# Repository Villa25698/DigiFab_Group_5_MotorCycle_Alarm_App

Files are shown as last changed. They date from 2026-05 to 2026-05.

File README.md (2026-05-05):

# MC Alarm — Motorcycle hazard-detection system

An accessible, retrofit-oriented warning device that detects motorcycle
speed wobble events and broadcasts a synchronised alert through three
independent channels: an LED hazard triangle on the bike, a wirelessly
switched relay that flashes the existing hazard lamps, and a full-screen
takeover on the rider's smartphone with a 5-second arming countdown.

Built for the ITI60020 *Digital Fabrication and Making* course at Østfold
University College, Spring 2026, in alignment with United Nations
Sustainable Development Goal Target 11.2 on safe, accessible, and
sustainable transport.

```
 ┌────────────────────┐    BLE GATT    ┌────────────────────────┐
 │  Flutter phone app │ ◄────────────► │  ESP32-C3  "master"    │
 └────────────────────┘                │  - MPU-6050 gyro       │
                                       │  - 8x8 LED matrix      │
                                       │  - 5W speaker (siren)  │
                                       │  - Test / OFF buttons  │
                                       └──────┬─────────────────┘
                                              │ ESP-NOW
                                              ▼
                                       ┌────────────────────────┐
                                       │  ESP32-C3 "slave"      │
                                       │  - 5V relay → hazards  │
                                       └────────────────────────┘
```

## Repository layout

| Folder | What it is |
| --- | --- |
| [`master/`](master) | ESP32-C3 firmware for the master node (gyro detection + siren + matrix + BLE + ESP-NOW) |
| [`slave_esp2_0/`](slave_esp2_0) | ESP32-C3 firmware for the hazard-relay slave |
| [`app/`](app) | Flutter companion app (Android) |
| [`ble_test/`](ble_test) | Minimal BLE-only test sketch — useful when bringing up a fresh ESP32-C3 |

## Hardware

**Electronics**
- 2× ESP32-C3 DevKitM-1
- 1× InvenSense MPU-6050 6-DoF IMU (I²C, addr `0x68`)
- 1× HT16K33 8x8 LED matrix backpack (I²C, addr `0x70`)
- 1× 5V single-channel relay module → motorcycle hazard light wiring
- 1× 40 mm 4 Ω 5 W speaker
- 2× metal pushbuttons (test alarm + off alarm)

**Mechanical (digitally fabricated)**
- 3D printed PETG enclosures: master case, slave case, and two pink end-cap holders for the indicator bulbs
- 3D printed TPU strap insert (25% infill, fuzzy-skin texture) for vibration damping and grip on the handlebar
- 3D printed PETG handlebar clamp halves (two diameter variants: 25.0 mm and 35.4 mm)
- Laser-cut MDF base panels closing the enclosures
- Laser-cut acrylic mounting plate on the Segway used as a mock motorcycle test platform

## Pin map (master)

The MPU-6050 and the LED matrix share **the same I²C bus** on GPIO 2/3,
distinguished by their different I²C addresses (`0x68` and `0x70`).

| Pin | Function |
| --- | --- |
| GPIO 4  | Test alarm button (INPUT_PULLUP) |
| GPIO 5  | Off alarm button (INPUT_PULLUP) |
| GPIO 7  | Speaker / piezo |
| GPIO 2  | Shared I²C SDA (MPU-6050 + matrix) |
| GPIO 3  | Shared I²C SCL (MPU-6050 + matrix) |

## Pin map (slave)

| Pin | Function |
| --- | --- |
| GPIO 18 | Relay control |

The relay polarity is set by two named constants at the top of
[`slave_esp2_0/slave_esp2_0.ino`](slave_esp2_0/slave_esp2_0.ino):

```cpp
const int RELAY_ON  = HIGH;   // pin level that lights the hazards
const int RELAY_OFF = LOW;    // pin level that turns them off
```

If the lights are on at boot, swap the two values.

## Firmware quick start

1. Install **Arduino IDE** with the **esp32 by Espressif Systems** board
   support package (core 3.x).
2. Install Arduino libraries: `Adafruit MPU6050`, `Adafruit Unified Sensor`,
   `Adafruit GFX`, `Adafruit LED Backpack`.
3. Open [`master/master.ino`](master/master.ino), select board
   `ESP32C3 Dev Module`, flash.
4. Open [`slave_esp2_0/slave_esp2_0.ino`](slave_esp2_0/slave_esp2_0.ino),
   set `#define NODE_ID 1` (each slave needs a unique id), flash.
5. The slave's MAC must match the `slave1[]` array in `master/master.ino`.
   Read the MAC from the slave's Serial Monitor at boot and update the
   master if needed.

## App quick start

See [`app/README.md`](app/README.md) — it pins the exact Flutter, Android
SDK, NDK, and plugin versions that work on Windows. **Use those versions
or you will spend hours fighting toolchain bugs.**

## BLE protocol

Service UUID: `a8a9b000-7c1f-4d2a-9e6b-2b0f3a7c0001`

| Char | UUID suffix | Props | Payload |
| --- | --- | --- | --- |
| alarmState  | `…0002` | Read, Notify | `uint8` 0/1 |
| wobbleEvent | `…0003` | Read, Notify | `uint8` counter |
| command | `…0004` | Write | `uint8` 0=stop, 1=manual, 2=toggle |
| nodeStatus  | `…0005` | Read, Notify | `uint8` bitmask, bit n = slave n+1 online |

## Wobble detection

The detector checks the strongest gyroscope axis per sample for sustained
back-and-forth motion. A trip requires **N sign reversals at >T rad/s
within W milliseconds** of each other.

| Profile | Threshold (T) | Sign reversals (N) | Window (W) |
| --- | --- | --- | --- |
| **Demo (default in this repo)** | 1.0 rad/s | 3 | 800 ms |
| **Production (recommended for on-bike use)** | 2.5 rad/s | 4 | 600 ms |

Demo values are easy to trigger by hand for testing. **Before mounting
on a real motorcycle, raise the values to the production profile** so road
surface vibration and engine harmonics don't cause false triggers. The
constants are at the top of `checkForWobble()` in
[`master/master.ino`](master/master.ino).

## Demo Guide
Follow these steps to power on the system and simulate motorcycle death wobble event

1. Powering on
   * Open the enclousures: Carefully open the lids of both the master(handlebar module) and the slave(light relay module)(CAUTION! Handle the Slave module (Lower box) carefullt when open, as interal components may be loose)
   * Acticate Power: Locate the battery switches and toggle them on.
   * Once the LEDs on the esp32 boards indicate power, screw the lids back on
   * Connect the 12v battery to a outlet
2. Simulating the death wobble
   * Place both hand on the handlebar grips
   * Mimic a motorcycle death wobble by making rapid left and right steering motions
   * You will have to do back and fourth motions until the LED Matric will display a hazard triangle. (It will also display on your phone if app us being used)
3. Managing the alarm
   * When the the alarm is triggered will you have a 5 second grace period to turn it off before the alarm starts. Press the Stop button on top of the master module or Stop button on your phone to turn prevent the siren and hazard light from activating
   * When the countdown reaches zero, will there be an aduble sound, matrix will keep blinking, and the hazard lights will start blinking. Press Stop on the box or phone to return the system to idle state. 

## Wobble alarm flow

1. **Idle**: master continuously samples the IMU.
2. **Detected**: wobble pattern matches the active profile → master sends
   a BLE wobble notify → phone pops the full-screen emergency takeover
   with a **5-second arming countdown**, master lights the hazard
   triangle on the LED matrix.
3. **Grace period (5 s)**: rider can abort by either:
   - pressing the **OFF button** on the master, OR
   - pressing **STOP** on the phone.
   Either action prevents the siren and the slave relay from firing.
4. **Alarm**: if 5 s elapse with no abort, the master fires the siren,
   broadcasts the alarm state to the slave over ESP-NOW, and the slave
   pulses its relay in synchrony, flashing the motorcycle's hazard
   lamps.
5. **Stop**: rider presses STOP (phone or button) → siren and relay
   silenced.
6. **Cooldown (3 s)**: wobble detection is suppressed so the speaker's own
   vibration cannot immediately re-trigger the alarm. After cooldown, the
   system returns to idle.

## Course paper

The accompanying 4-6 page extended academic abstract describes the
design rationale, related work, fabrication process, validation
results, and discussion. Submitted as part of the ITI60020 exam, May
2026.

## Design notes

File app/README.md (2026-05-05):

# MC Alarm — Flutter companion app

Connects to the MC-Alarm ESP32-C3 gateway over BLE, shows live status, and
takes over the screen when a speed-wobble event fires.

```
 Phone (this app)
     │  BLE GATT
 ESP32-C3 "master"  ──────►  ESP-NOW  ──────► ESP32-C3 slave nodes
```

## Required toolchain (READ THIS BEFORE INSTALLING)

We hit a wall of Windows long-path / Dart compiler bugs on newer Flutter
versions. Use **exactly** these versions and you'll skip the pain.

| Tool | Version | Notes |
| --- | --- | ----- |
| Flutter SDK | **3.24.5 (stable)** | Newer 3.27+ has Windows long-path bugs and a JSON-escape bug in `.flutter-plugins-dependencies` that breaks plugin discovery |
| Dart | bundled with Flutter | comes with 3.24.5 — don't install separately |
| Android Studio | Hedgehog (2023.1) or newer | needed for the Android SDK + cmdline-tools, not as the editor |
| Android SDK | API 34 / build-tools 34 | install via Android Studio's SDK Manager |
| Android NDK | **27.0.12077973** | required by `flutter_local_notifications` — set in `android/app/build.gradle.kts` |
| Java | 17 | Flutter 3.24 picks this up from Android Studio's bundled JDK |
| `flutter_blue_plus` | **1.31.17** | 1.32+ split into platform packages with new Gradle conventions; stay on 1.31.x |
| `permission_handler` | **11.3.1** | works cleanly with Flutter 3.24 |
| `flutter_local_notifications` | **17.2.3** | 17.0.x has a Java compile error (`bigLargeIcon ambiguous`) |

### Get Flutter 3.24.5

```bash
git clone https://github.com/flutter/flutter.git -b 3.24.5 C:\flutter
# add C:\flutter\bin to your PATH
flutter --version    # verify "Flutter 3.24.5 • channel stable"
```

If you already have a different Flutter version installed, switch with:
```bash
flutter version 3.24.5
```

### Avoid deep folder paths on Windows

Clone the repo to a short path (e.g. `C:\mc-alarm` not
`C:\Users\you\Documents\GitHub\…`). Flutter's plugin tooling chokes on
paths longer than ~150 chars on Windows.

## First-time setup

Flutter doesn't ship the platform scaffolds in source control, so generate
them once — then let the files we've committed here take over.

```bash
cd app
flutter create . --platforms=android,ios --org com.digifab --project-name mc_alarm
flutter pub get
```

`flutter create .` generates `android/`, `ios/`, `build.gradle`, etc. without
touching existing files — so `lib/`, `pubspec.yaml`, `analysis_options.yaml`
and `android/app/src/main/AndroidManifest.xml` stay as provided.

### iOS only — merge Info.plist keys

Open `ios/Runner/Info.plist` and add the keys listed in
`ios/Runner/Info.plist.additions`. They grant Bluetooth + Location
permission strings that Apple requires at App Store submission time.

### Android only — minimum SDK

Edit `android/app/build.gradle`, set:
```gradle
defaultConfig {
    minSdkVersion 23   // flutter_blue_plus requires 21+, we use 23 for safety
    targetSdkVersion 34
}
```

## Running

```bash
flutter run -d <device>           # pick a real Android phone for BLE
```

BLE does not work on the Android emulator — test on a real phone.

## GATT protocol

Service UUID: `a8a9b000-7c1f-4d2a-9e6b-2b0f3a7c0001`

| Characteristic | UUID suffix | Props | Payload |
| --- | --- | ----- | --- |
| alarmState  | `...0002` | Read, Notify | `uint8` 0/1 |
| wobbleEvent | `...0003` | Notify | `uint8` counter |
| command | `...0004` | Write | `uint8` 0=stop, 1=manual, 2=toggle hazard |
| nodeStatus  | `...0005` | Read, Notify | `uint8` bitmask, bit n = slave n+1 online |

Source of truth: [master/master.ino](../master/master.ino).

## Emergency screen behaviour

When the gateway sends a `wobbleEvent` notification:

- **Foreground**: the app pushes `WobbleScreen` over the current route.
- **Background (Android)**: a high-priority `USE_FULL_SCREEN_INTENT`
  notification fires. Android promotes our activity to the foreground
  (`showWhenLocked=true`, `turnScreenOn=true` in the manifest). User can
  also tap the persistent notification.
- **Background (iOS)**: a critical-sound notification is shown. iOS does
  not permit an app to force itself to the foreground — this is a
  platform limitation, not a bug. The user must tap the banner.

The `STOP` button on the wobble screen writes `command=0` back to the
gateway, which silences the siren and clears the relays via ESP-NOW.

## Directory layout

```
lib/
├── main.dart                 App entry, root router, wobble listener
├── bluetooth/
│   ├── ble_constants.dart    UUIDs & command codes (kept in sync with firmware)
│   └── ble_service.dart      ChangeNotifier-owned BLE connection
├── services/
│   └── notification_service.dart   Full-screen-intent notification plumbing
├── screens/
│   ├── welcome_screen.dart
│   ├── permissions_screen.dart
│   ├── scan_screen.dart
│   ├── dashboard_screen.dart
│   └── wobble_screen.dart
└── theme/app_theme.dart      High-contrast, oversized-touch-target theme
```

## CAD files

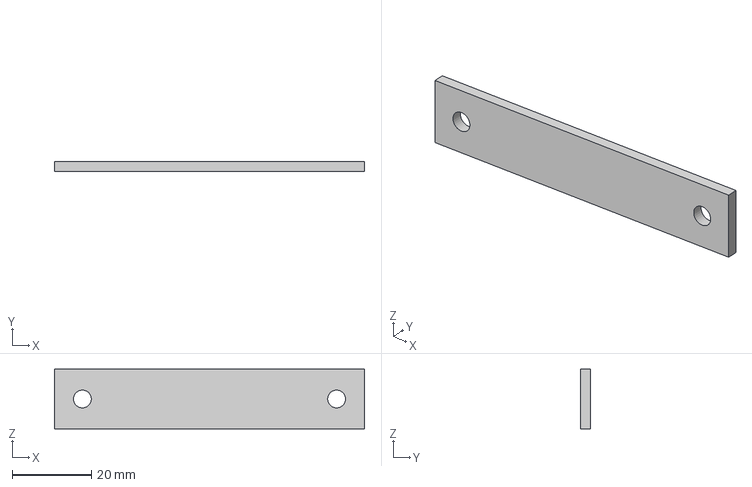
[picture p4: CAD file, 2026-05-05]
3d_models/reim_main.3mf
78.0 x 2.50 x 15.0 mm

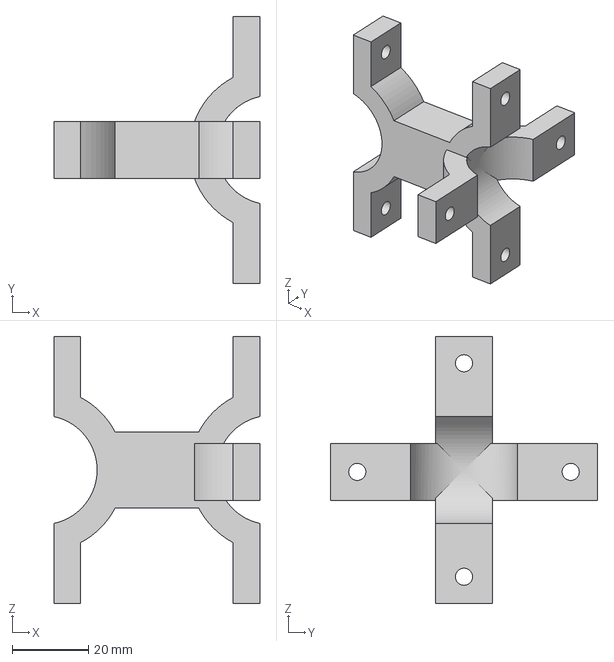
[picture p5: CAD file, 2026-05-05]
3d_models/ClampMainWstaff.3mf
54.0 x 70.0 x 70.0 mm

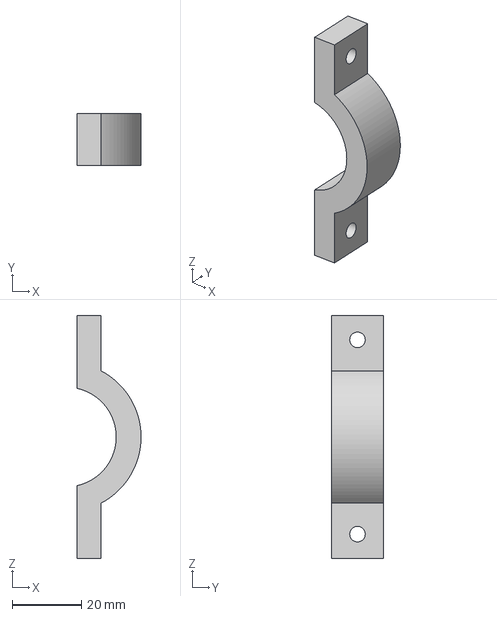
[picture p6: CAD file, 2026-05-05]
3d_models/ClampMain.3mf
18.5 x 15.0 x 70.0 mm

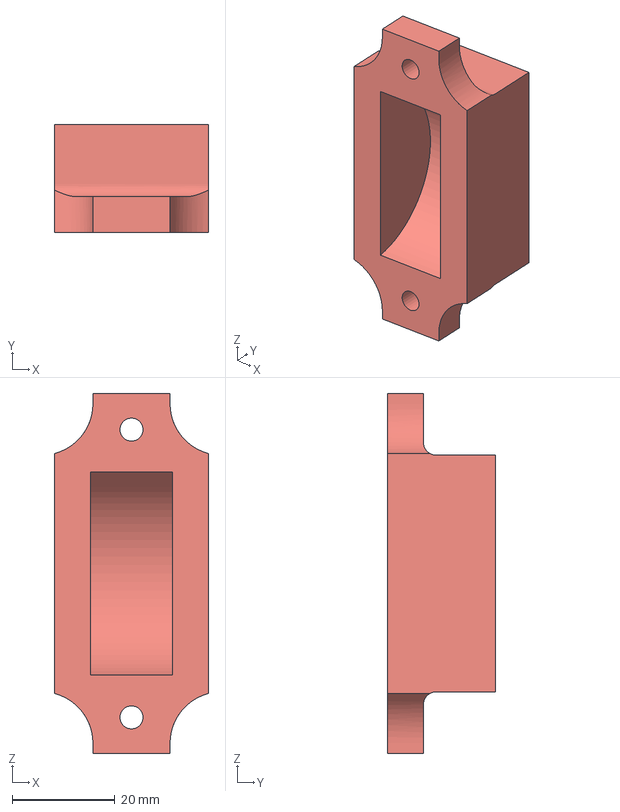
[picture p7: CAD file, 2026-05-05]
3d_models/attachment.3mf
30.0 x 21.0 x 70.0 mm

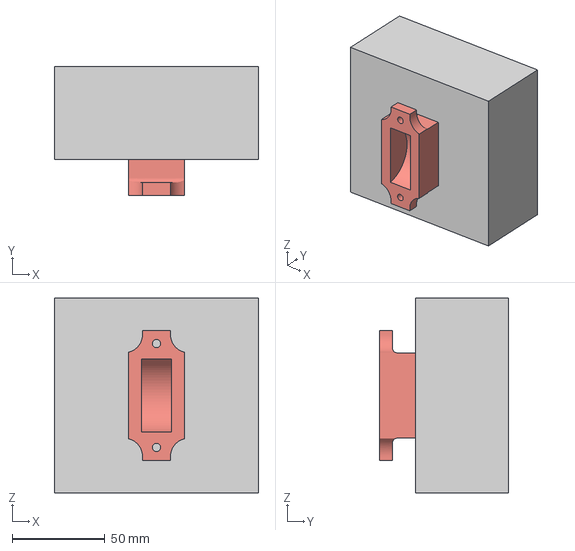
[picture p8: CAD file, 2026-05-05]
3d_models/User_box_w_attachment.3mf
110.0 x 69.5 x 105.0 mm

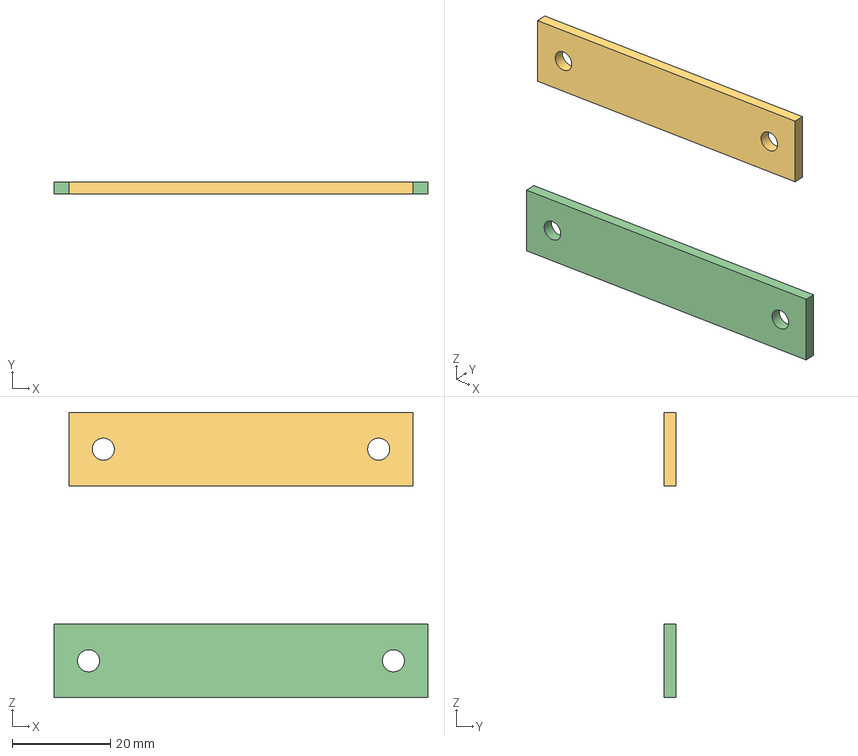
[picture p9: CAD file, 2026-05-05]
3d_models/straps_w_flat.3mf
76.0 x 2.50 x 58.0 mm

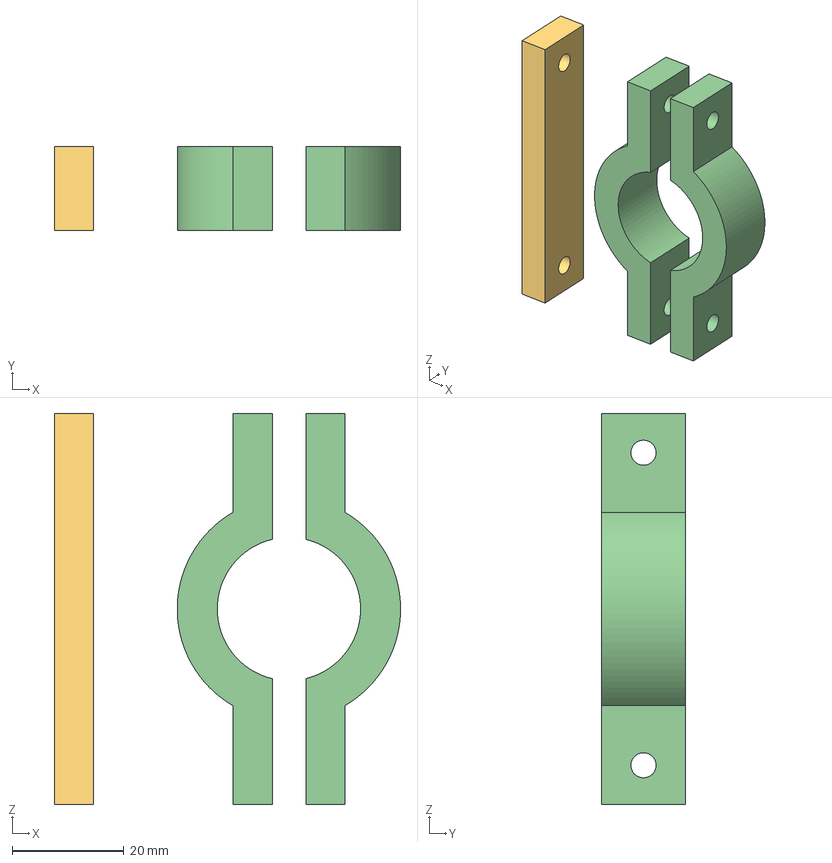
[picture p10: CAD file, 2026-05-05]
3d_models/clamps_w_flat.3mf
62.0 x 15.0 x 70.0 mm

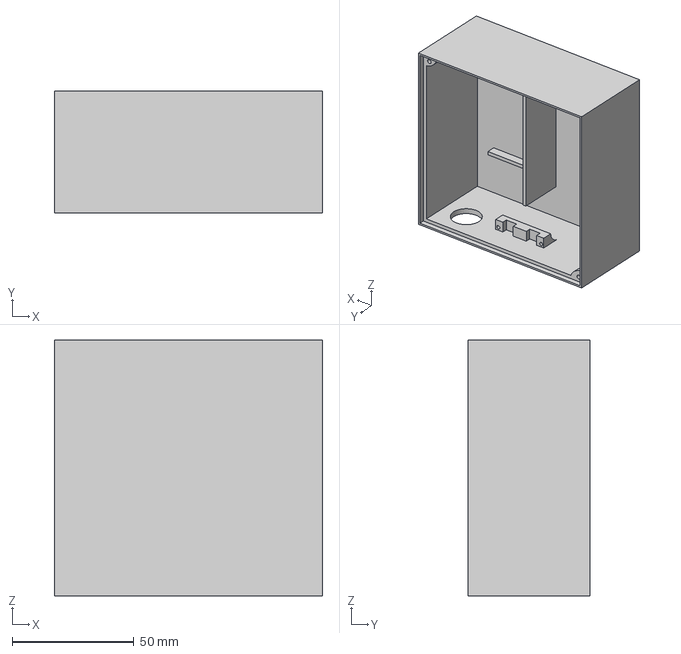
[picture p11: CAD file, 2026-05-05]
3d_models/user_box.3mf
110.0 x 50.0 x 105.0 mm

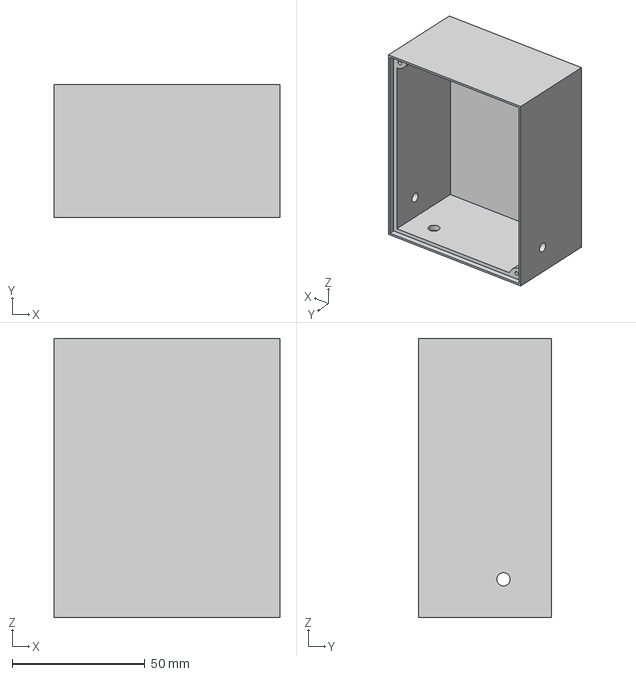
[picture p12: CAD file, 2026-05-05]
3d_models/comp_box.3mf
85.0 x 50.0 x 105.0 mm

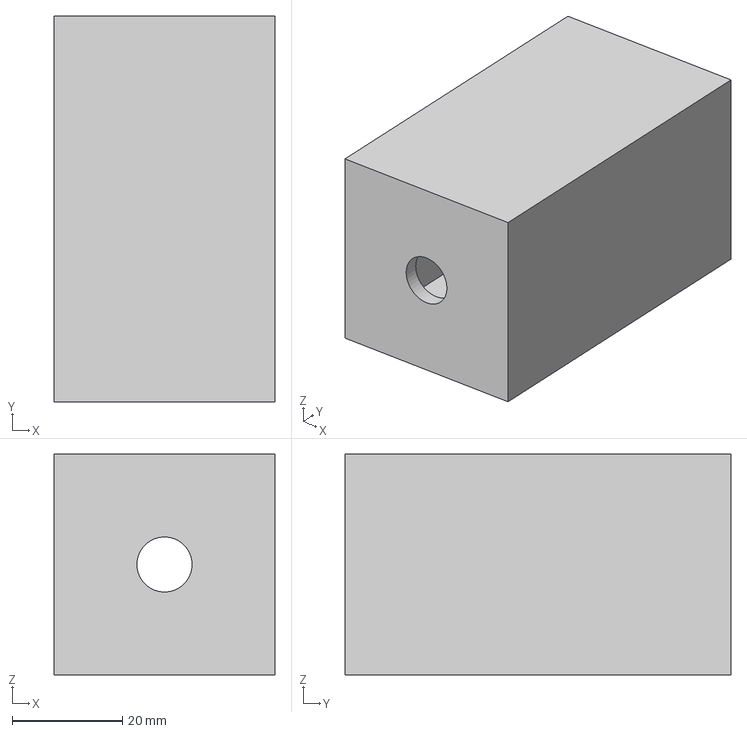
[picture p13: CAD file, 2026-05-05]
3d_models/light_attachment.3mf
40.0 x 70.0 x 40.0 mm

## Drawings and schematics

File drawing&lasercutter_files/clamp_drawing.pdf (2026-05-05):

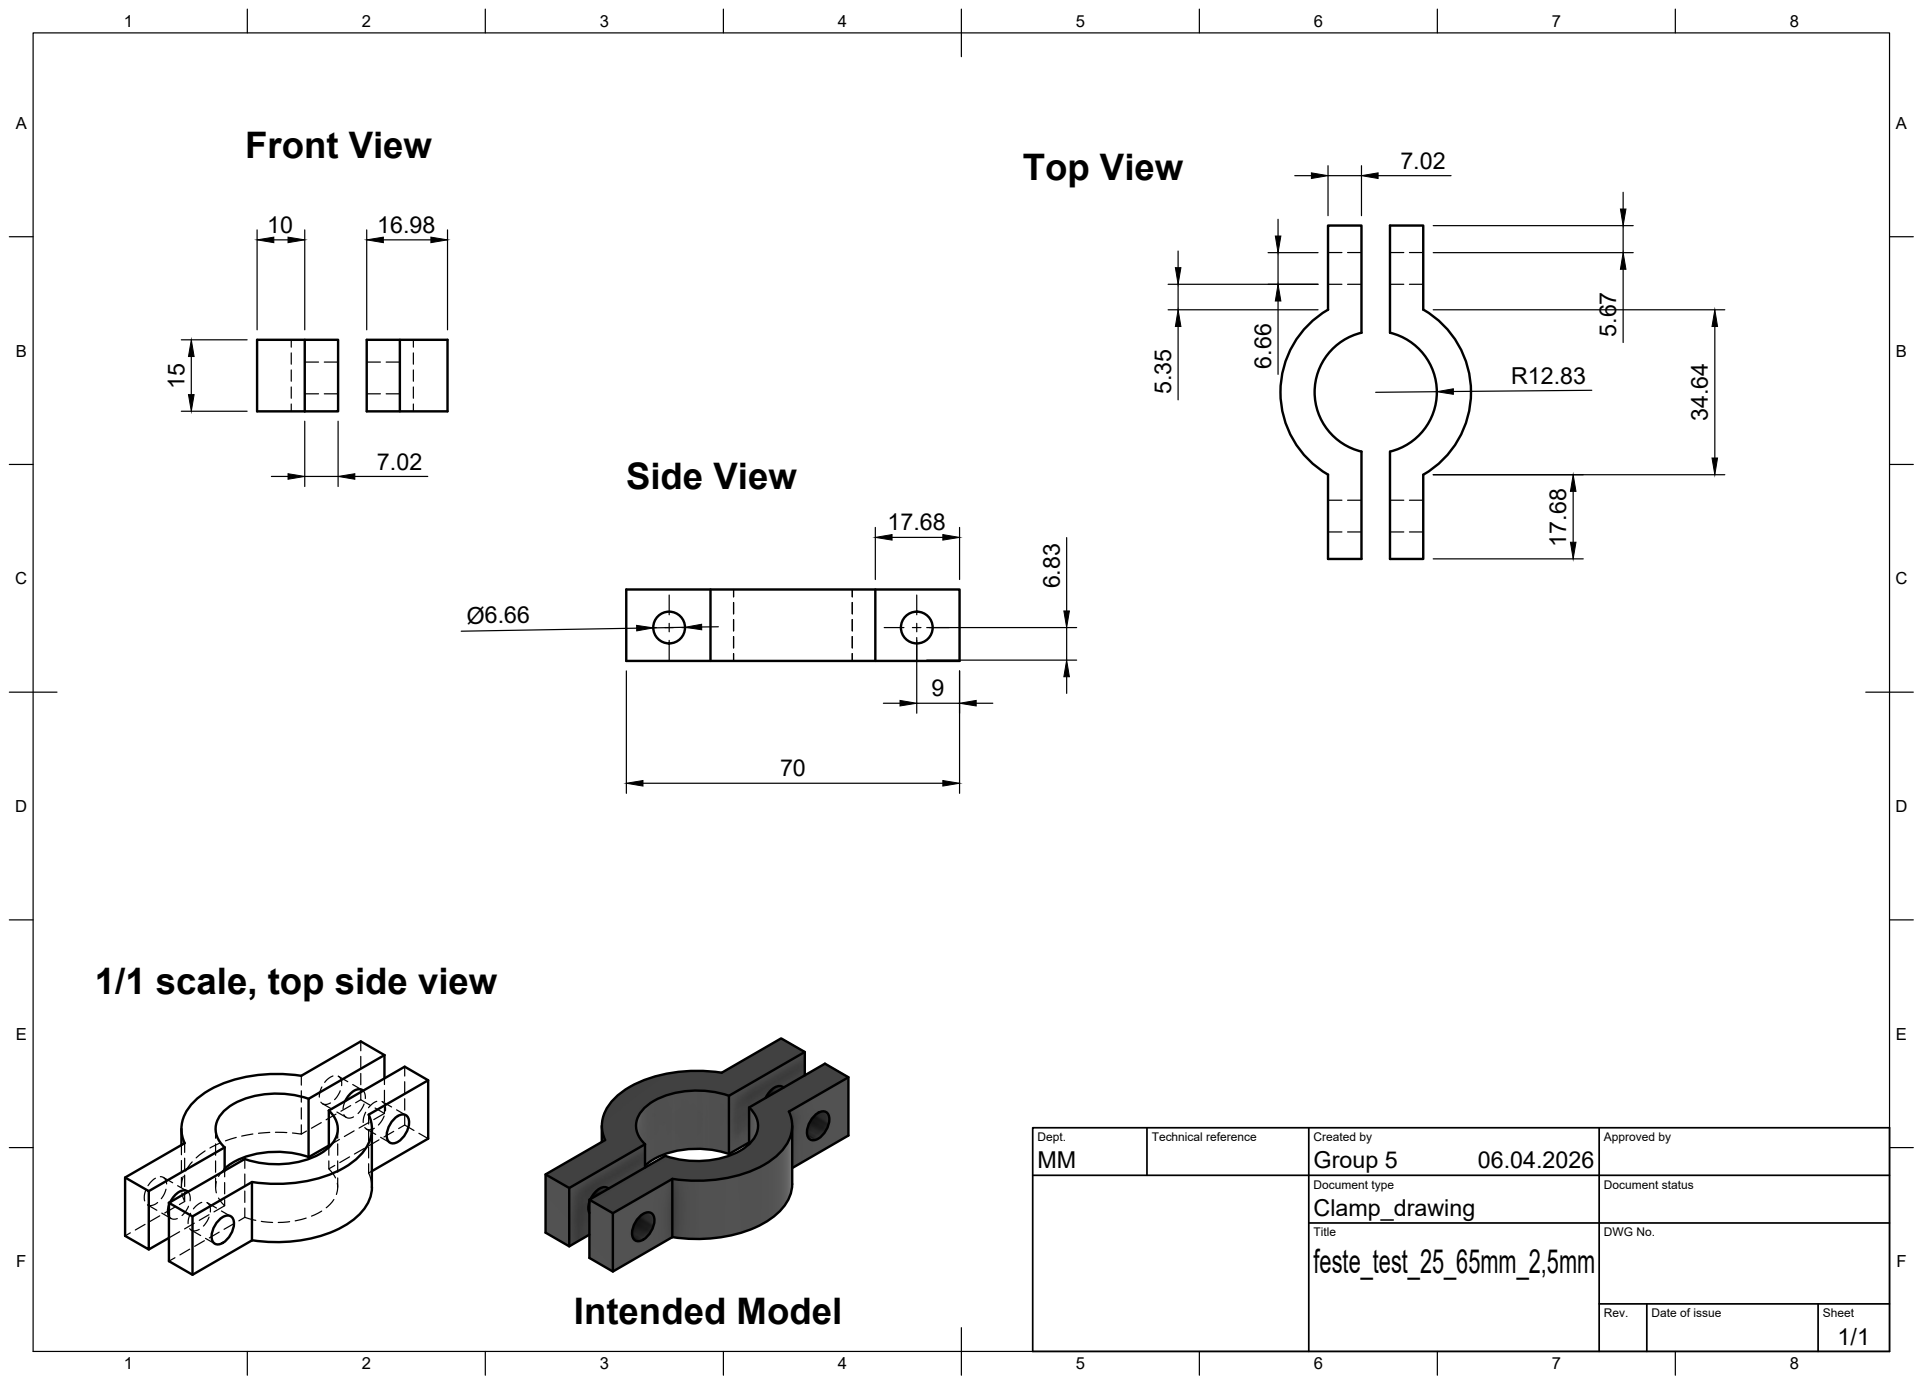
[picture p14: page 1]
Title; DWG No.; Rev.; Date of issue; Sheet; Group 5 15; Front View; Side View; Top View; Intended Model

1/1 scale, top side view

Dept. | Technical reference | Created by 06.04.2026 | Approved by

Document type Clamp_drawing | Document status

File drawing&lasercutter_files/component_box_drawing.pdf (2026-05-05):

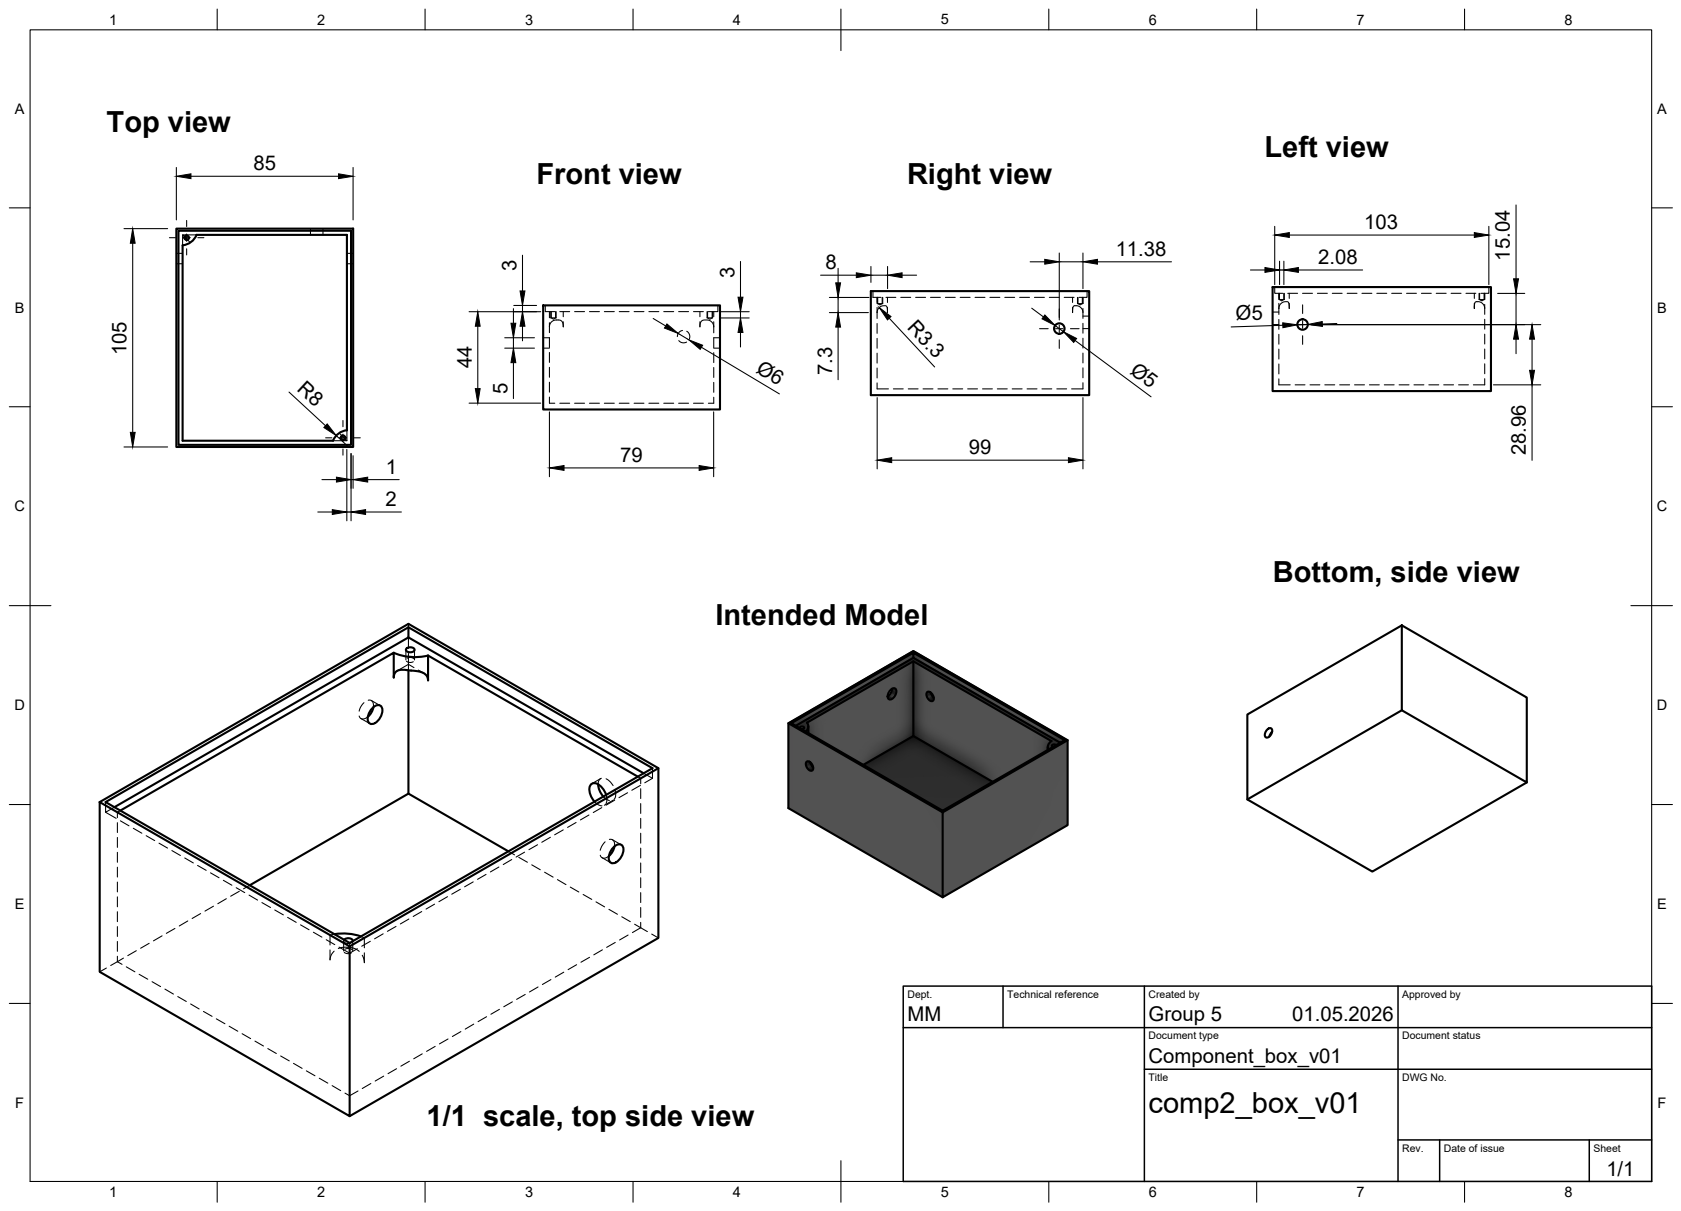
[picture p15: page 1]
Title; DWG No.; Rev.; Date of issue; Sheet; Top view; Front view; Right view; Left view; Intended Model

Bottom, side view

Dept. MM | Technical reference | Created by Group 5 01.05.2026 | Approved by

Document type Component_box_v01 | Document status

1/1 scale, top side view

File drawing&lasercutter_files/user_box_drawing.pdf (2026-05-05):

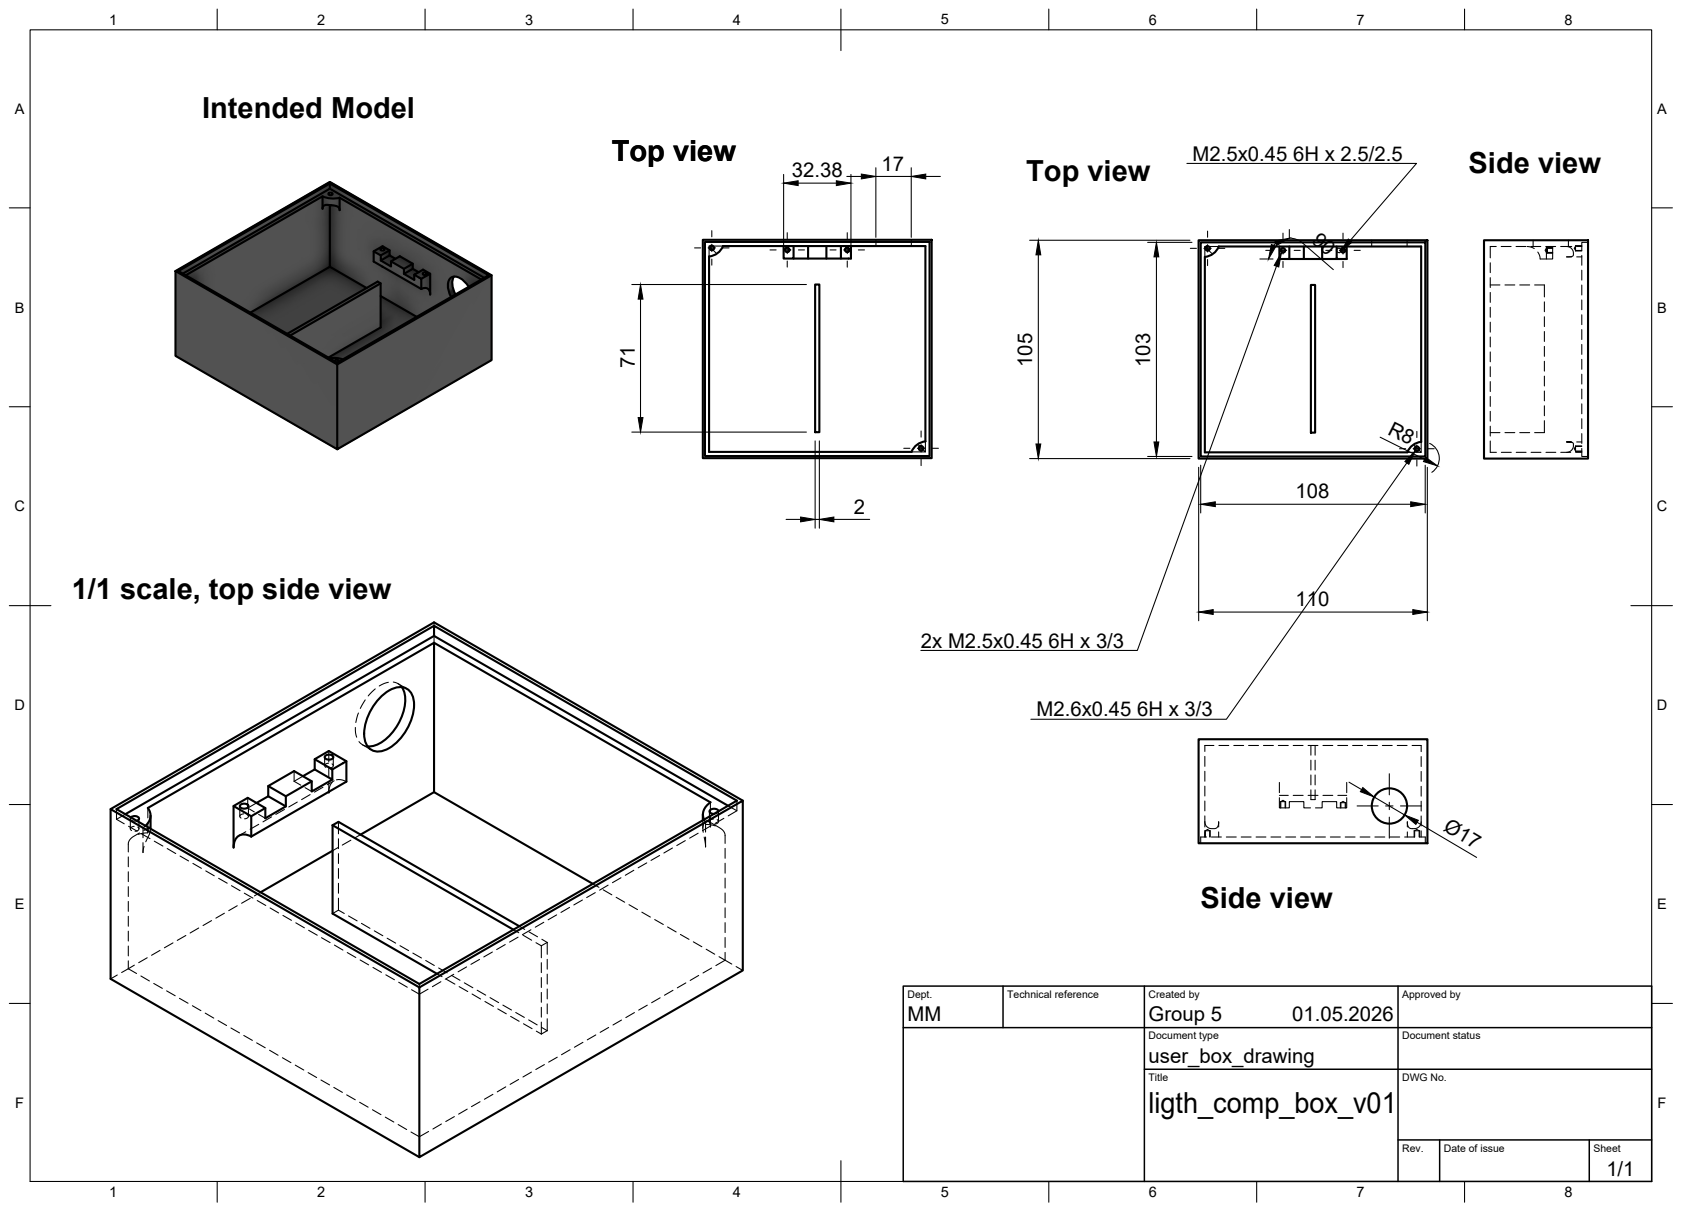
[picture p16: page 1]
Title; DWG No.; Rev.; Date of issue; Sheet; Intended Model; Top view; Side view

1/1 scale, top side view

Dept. MM | Technical reference | Created by Group 5 01.05.2026 | Approved by

Document type user_box_drawing | Document status

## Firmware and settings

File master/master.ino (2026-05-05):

// ============================================================================
//  MC Alarm — Master (Gateway) firmware
//  Board: ESP32-C3 DevKitM-1
//  Arduino-ESP32 core: 3.x  (callback signatures changed in 3.0)
// ============================================================================
//
//  WHAT THIS DEVICE DOES
//  ---------------------
//  This is the "brain" of the motorcycle alarm system. It is the only board
//  on the bike that has sensors and outputs. It does four things at once:
//
//    1. Watches the MPU-6050 gyro for a death-wobble pattern.
//    2. When a wobble fires it sounds a siren on the speaker and lights a
//       hazard triangle on an 8x8 LED matrix.
//    3. Sends an "alarm on" message to the slave board over ESP-NOW so the
//       slave can switch on the bike's hazard lights via a relay.
//    4. Talks to the rider's phone (Flutter app) over BLE so the phone can
//       show what's happening and let the rider stop the alarm.
//
//
//  HOW DATA FLOWS
//  --------------
//
//      gyro         buttons        LED matrix     speaker
//        |             |               ^             ^
//        v             v               |             |
//      ┌───────────────────────────────────────────────┐
//      │              MASTER (this code)              │
//      └─────────────┬───────────────────┬─────────────┘
//                    │                   │
//                BLE GATT            ESP-NOW
//                    │                   │
//                    v                   v
//                  PHONE              SLAVE  ─►  bike hazard relay
//
//
//  BLE GATT LAYOUT
//  ---------------
//  Service UUID                a8a9b000-7c1f-4d2a-9e6b-2b0f3a7c0001
//
//  Characteristic    Suffix    Properties     Payload
//  ----------------  --------  -------------  ------------------------------
//  alarmState        ...0002   READ, NOTIFY   uint8  0=off, 1=on
//  wobbleEvent       ...0003   READ, NOTIFY   uint8  counter (++ every wobble)
//  command           ...0004   WRITE          uint8  0=stop, 1=manual on,
//                                                    2=toggle
//  nodeStatus        ...0005   READ, NOTIFY   uint8  bitmask, bit n = slave
//                                                    n+1 online
//
//
//  ESP-NOW MESSAGE
//  ---------------
//  Master and slave share this 3-byte struct (see struct_message). msgType
//  tells the receiver what the message means:
//
//    0x01 MSG_ALARM_STATE  master -> slave : "alarm is now on/off"
//    0x02 MSG_PING         master -> slave : "are you alive?"
//    0x03 MSG_HEARTBEAT    slave  -> master: "yes I'm alive, I am node N"
//
// ============================================================================


// ----------------------------------------------------------------------------
// 1. INCLUDES
// ----------------------------------------------------------------------------
#include <esp_now.h>                  // peer-to-peer wifi protocol used to talk to the slave
#include <WiFi.h>                     // ESP-NOW needs the wifi radio to be in STA mode
#include <Adafruit_MPU6050.h>         // gyro + accel driver
#include <Adafruit_Sensor.h>          // base class used by MPU6050 (sensors_event_t)
#include <Wire.h>                     // I2C driver — both gyro and matrix use it
#include <Adafruit_GFX.h>             // graphics primitives (drawLine etc.) for the matrix
#include "Adafruit_LEDBackpack.h"     // driver for the HT16K33 chip on the matrix module

#include <BLEDevice.h>                // BLE stack (we act as a GATT server)
#include <BLEServer.h>                // BLEServer + BLEServerCallbacks
#include <BLEUtils.h>                 // misc helpers used by the BLE stack
#include <BLE2902.h>                  // CCC descriptor — needed for any NOTIFY characteristic


// ----------------------------------------------------------------------------
// 2. PIN CONFIGURATION
// ----------------------------------------------------------------------------
// Buttons use INPUT_PULLUP — wiring is:
//     button leg 1 -> GPIO pin
//     button leg 2 -> GND
// Pressed = pin reads LOW, released = pin reads HIGH (held high by internal pull-up).
const int TEST_BUTTON_PIN = 4;        // press to manually fire the alarm (for demos)
const int OFF_BUTTON_PIN  = 5;        // press to silence the alarm

const int speakerPin      = 7;        // siren — driven with tone() to make a square wave

// MPU-6050 (I2C addr 0x68) and the LED matrix (0x70) live on the SAME I2C bus.
// I2C is multi-drop: many devices, two wires, addresses tell them apart.
const int I2C_SDA         = 2;
const int I2C_SCL         = 3;


// ----------------------------------------------------------------------------
// 3. ALARM STATE
// ----------------------------------------------------------------------------
//
// The alarm has THREE possible states, in order:
//
//   1. IDLE                alarmActive = false, wobblePending = false
//      Wobble detection is running. Nothing is sounding.
//
//   2. PENDING             alarmActive = false, wobblePending = true
//      A wobble was just detected. The phone has already been notified and
//      is showing the 5-second countdown. The siren has NOT fired yet.
//      The rider can press OFF (local button) or STOP (in app) to abort.
//      If 5 seconds pass with no abort, we transition to ACTIVE.
//
//   3. ACTIVE              alarmActive = true,  wobblePending = false
//      Siren on, matrix flashing, slave told to flash hazards. Stays here
//      until OFF button or app STOP.
//
// After leaving ACTIVE we enter a 3-second cooldown where we ignore the
// gyro completely — otherwise vibration from the speaker that just stopped
// would re-trigger the wobble detector immediately.
//
bool alarmActive = false;
bool wobblePending = false;
unsigned long wobblePendingUntil = 0;       // millis() value at which pending becomes ACTIVE
const unsigned long WOBBLE_GRACE_MS = 5000; // length of the pending window

unsigned long alarmStoppedAt = 0;           // millis() value of the last off-transition (0 = never)
const unsigned long POST_ALARM_COOLDOWN = 3000;  // ignore gyro for this long after stop

// At boot, the gyro takes a moment to warm up and stabilize. Don't even
// look at it for the first few seconds.
const unsigned long STARTUP_GRACE_MS = 3000;

// Set to true only if the MPU responded on I2C at boot. If it's false (bad
// wiring, dead chip, …) wobble detection is disabled entirely so we can't
// false-fire on garbage memory readings from the unconnected sensor.
bool mpuOk = false;

// Counts every wobble detection ever. Sent to the phone over BLE so the
// app can tell "this is a new wobble" vs "I'm just seeing the cached value
// after reconnect" by checking whether the counter changed.
uint8_t wobbleCounter = 0;


// ----------------------------------------------------------------------------
// 4. SENSOR / DISPLAY OBJECTS
// ----------------------------------------------------------------------------
Adafruit_MPU6050 mpu;
Adafruit_8x8matrix matrix = Adafruit_8x8matrix();

// Matrix blink scheduling. We use millis() instead of delay() so the rest
// of the loop (BLE, ESP-NOW, buttons) keeps running while the triangle blinks.
unsigned long lastBlinkTime = 0;
const int     blinkInterval = 400;          // ms — half period (on for 400 ms, off for 400 ms)
bool matrixState = false;                   // true = triangle showing, false = blank


// ----------------------------------------------------------------------------
// 5. ESP-NOW PROTOCOL (master <-> slave)
// ----------------------------------------------------------------------------
#define MSG_ALARM_STATE 0x01
#define MSG_PING        0x02
#define MSG_HEARTBEAT   0x03

// __attribute__((packed)) tells the compiler not to insert padding bytes.
// Both master and slave see the exact same 3-byte layout in memory.
typedef struct __attribute__((packed)) struct_message {
    uint8_t msgType;        // one of MSG_* above
    bool    alarmActive;    // for MSG_ALARM_STATE; also echoed in MSG_PING
    uint8_t nodeId;         // master sends 0; slave reports its own NODE_ID in heartbeats
} struct_message;

struct_message myData;                  // outgoing buffer (re-used)
esp_now_peer_info_t peerInfo;           // used during esp_now_add_peer()

// Hard-coded slave MAC. Read it once from the slave's Serial Monitor at boot
// and put it here. To support more slaves, add slave2[] / slave3[] and bump
// NUM_SLAVES.
uint8_t slave1[] = {0xAC, 0xEB, 0xE6, 0x80, 0xF3, 0xE4};
#define NUM_SLAVES 1

// For each slave we remember when its last heartbeat arrived. If it's been
// longer than HEARTBEAT_TIMEOUT we treat the slave as offline.
unsigned long lastHeartbeat[NUM_SLAVES] = {0};
const unsigned long HEARTBEAT_TIMEOUT   = 5000;   // ms
const unsigned long PING_INTERVAL       = 1500;   // ms — how often we ping each slave
unsigned long lastPingSent = 0;
uint8_t lastNodeStatus = 0xFF;          // sentinel — forces a publish on first loop


// ----------------------------------------------------------------------------
// 6. BLE CONSTANTS
// ----------------------------------------------------------------------------
// All UUIDs share the prefix a8a9b000-…-2b0f3a7c000X so they group nicely
// in BLE scanners.
#define SVC_UUID         "a8a9b000-7c1f-4d2a-9e6b-2b0f3a7c0001"
#define CHAR_ALARM_UUID  "a8a9b000-7c1f-4d2a-9e6b-2b0f3a7c0002"
#define CHAR_WOBBLE_UUID "a8a9b000-7c1f-4d2a-9e6b-2b0f3a7c0003"
#define CHAR_CMD_UUID    "a8a9b000-7c1f-4d2a-9e6b-2b0f3a7c0004"
#define CHAR_NODES_UUID  "a8a9b000-7c1f-4d2a-9e6b-2b0f3a7c0005"

// Pointers — actual objects are created in setup().
BLECharacteristic *chrAlarm  = nullptr;     // alarm on/off, master->phone
BLECharacteristic *chrWobble = nullptr;     // wobble counter, master->phone
BLECharacteristic *chrCmd    = nullptr;     // commands, phone->master
BLECharacteristic *chrNodes  = nullptr;     // slave online bitmask, master->phone

bool bleClientConnected = false;            // updated by ServerCallbacks


// ----------------------------------------------------------------------------
// 7. FORWARD DECLARATIONS
// ----------------------------------------------------------------------------
// These exist because the BLE callback classes (defined just below) call
// functions that are written further down in the file. C/C++ requires us
// to either declare them up front or move the definitions above the use.
void setAlarm(bool on, const char *reason);
void publishAlarmState();
void publishNodeStatus(uint8_t mask);


// ----------------------------------------------------------------------------
// 8. BLE CALLBACKS
// ----------------------------------------------------------------------------
// Fires when a phone connects or disconnects.
class ServerCallbacks : public BLEServerCallbacks {
  void onConnect(BLEServer*) override {
    bleClientConnected = true;
    Serial.println("BLE: phone connected");
  }
  void onDisconnect(BLEServer*) override {
    bleClientConnected = false;
    Serial.println("BLE: phone disconnected, restarting advertising");
    // After a disconnect the BLE stack stops advertising automatically. We
    // need to restart it so the phone can re-find us next time.
    BLEDevice::startAdvertising();
  }
};

// Fires when the phone WRITES to the command characteristic (one-byte cmd).
class CmdCallback : public BLECharacteristicCallbacks {
  void onWrite(BLECharacteristic *c) override {
    String v = c->getValue();
    if (v.length() < 1) return;
    uint8_t cmd = (uint8_t)v[0];
    Serial.printf("BLE cmd received: %u\n", cmd);
    switch (cmd) {
      case 0:    // stop
        // STOP also has to abort a wobble that's in its grace period —
        // otherwise the rider thinks they cancelled it but the alarm
        // fires anyway after 5 seconds.
        if (wobblePending) {
          wobblePending  = false;
          alarmStoppedAt = millis();      // start the cooldown
          // Clear the warning triangle — alarm wasn't actually firing yet.
          matrix.clear();
          matrix.writeDisplay();
          matrixState = false;
          Serial.println("Wobble cancelled by app during grace period");
        }
        setAlarm(false, "app stop");
        break;
      case 1:    // manual on
        setAlarm(true, "app manual");
        break;
      case 2:    // toggle
        setAlarm(!alarmActive, "app toggle");
        break;
    }
  }
};


// ----------------------------------------------------------------------------
// 9. ESP-NOW CALLBACKS
// ----------------------------------------------------------------------------
// Note: signatures changed in Arduino-ESP32 core 3.0. The old (uint8_t* mac, …)
// signatures will compile but never be called by the new core.

// Called after every esp_now_send() — used only for diagnostics.
void OnDataSent(const wifi_tx_info_t *info, esp_now_send_status_t status) {
  if (status != ESP_NOW_SEND_SUCCESS) Serial.println("ESP-NOW send failed");
}

// Called whenever an ESP-NOW packet arrives. We only care about heartbeats
// from slaves.
void OnDataRecv(const esp_now_recv_info *info, const uint8_t *data, int len) {
  if (len != sizeof(struct_message)) return;     // wrong size = not our message
  struct_message incoming;
  memcpy(&incoming, data, sizeof(incoming));
  if (incoming.msgType == MSG_HEARTBEAT) {
    uint8_t id = incoming.nodeId;
    if (id >= 1 && id <= NUM_SLAVES) {
      lastHeartbeat[id - 1] = millis();
    }
  }
}


// ----------------------------------------------------------------------------
// 10. ESP-NOW SENDERS  (master -> slaves)
// ----------------------------------------------------------------------------
// Tell every registered slave whether the alarm is on or off.
void sendAlarmState(bool state) {
  myData.msgType     = MSG_ALARM_STATE;
  myData.alarmActive = state;
  myData.nodeId      = 0;
  esp_now_send(0, (uint8_t *)&myData, sizeof(myData));   // 0 = broadcast to all peers
}

// "Are you alive?" message. Slave replies with MSG_HEARTBEAT.
void sendPing() {
  myData.msgType     = MSG_PING;
  myData.alarmActive = alarmActive;     // also use the ping to (re)sync state
  myData.nodeId      = 0;
  esp_now_send(0, (uint8_t *)&myData, sizeof(myData));
}


// ----------------------------------------------------------------------------
// 11. BLE PUBLISHERS  (master -> phone)
// ----------------------------------------------------------------------------
// Each helper writes a 1-byte value into the characteristic, then NOTIFIES
// any connected phone. setValue() updates the cache (so a later READ
// returns the right value even if the phone wasn't subscribed).
void publishAlarmState() {
  if (!chrAlarm) return;
  uint8_t v = alarmActive ? 1 : 0;
  chrAlarm->setValue(&v, 1);
  if (bleClientConnected) chrAlarm->notify();
}

void publishWobble() {
  if (!chrWobble) return;
  chrWobble->setValue(&wobbleCounter, 1);
  if (bleClientConnected) chrWobble->notify();
}

void publishNodeStatus(uint8_t mask) {
  if (!chrNodes) return;
  chrNodes->setValue(&mask, 1);
  if (bleClientConnected) chrNodes->notify();
}


// ----------------------------------------------------------------------------
// 12. CENTRAL ALARM-STATE TRANSITION
// ----------------------------------------------------------------------------
// EVERY alarm on/off change goes through this one function. That way the
// siren, the matrix, the slave, and the phone always agree. If you call
// tone() / digitalWrite() / sendAlarmState() yourself somewhere else, you
// will get out-of-sync state — don't do it.
void setAlarm(bool on, const char *reason) {
  if (alarmActive == on) return;        // nothing to do — already in this state
  alarmActive = on;

  if (on) {
    tone(speakerPin, 1200);             // siren tone — change frequency for a different pitch
    lastBlinkTime = millis();           // reset the blink timer so the matrix starts ON immediately
  } else {
    noTone(speakerPin);                 // stop the PWM
    digitalWrite(speakerPin, LOW);      // belt-and-suspenders — make sure the pin is silent
    matrix.clear();
    matrix.writeDisplay();
    alarmStoppedAt = millis();          // start the cooldown for the wobble detector
  }

  // Tell the slave and the phone about the change.
  sendAlarmState(on);
  publishAlarmState();
  Serial.printf("Alarm %s (%s)\n", on ? "ON" : "OFF", reason);
}


// ----------------------------------------------------------------------------
// 13. LED MATRIX — HAZARD TRIANGLE
// ----------------------------------------------------------------------------
// Draws a simple triangle outline pointing up. Coordinates are (x, y) on
// the 8x8 grid, (0,0) is the top-left corner.
void drawTriangle() {
  matrix.clear();
  matrix.drawLine(3, 0, 4, 0, LED_ON);  // top apex (2 pixels wide)
  matrix.drawLine(3, 0, 0, 7, LED_ON);  // left side
  matrix.drawLine(4, 0, 7, 7, LED_ON);  // right side
  matrix.drawLine(0, 7, 7, 7, LED_ON);  // base
  matrix.writeDisplay();
}
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
void loop() {

  // ---- (a) physical buttons ----
  // Pressed = LOW (we use INPUT_PULLUP). The 250 ms delay after a press is
  // a poor man's debounce — it also limits how fast you can mash the button.
  if (digitalRead(TEST_BUTTON_PIN) == LOW) {
    setAlarm(true, "local button");
    delay(250);
  }
  if (digitalRead(OFF_BUTTON_PIN) == LOW) {
    // OFF also aborts a pending wobble before its 5-second grace expires.
    if (wobblePending) {
      wobblePending  = false;
      alarmStoppedAt = millis();
      // Clear the warning triangle — alarm wasn't actually firing yet.
      matrix.clear();
      matrix.writeDisplay();
      matrixState = false;
      Serial.println("Wobble cancelled by OFF button during grace period");
    }
    setAlarm(false, "local button");
    delay(250);
  }

  // ---- (b) wobble detection ----
  // Five conditions all have to be true for us to even look at the gyro:
  //   1. The MPU was actually found at boot (no garbage data).
  //   2. The alarm isn't already firing.
  //   3. We're not already in the pending grace period.
  //   4. We've waited the post-alarm cooldown.
  //   5. We've waited the startup grace.
  bool wobbleAllowed = mpuOk
                    && !alarmActive
                    && !wobblePending
                    && millis() > STARTUP_GRACE_MS
                    && (alarmStoppedAt == 0
                        || (millis() - alarmStoppedAt) > POST_ALARM_COOLDOWN);
  if (wobbleAllowed && checkForWobble()) {
    wobbleCounter++;
    publishWobble();                              // tell the phone NOW so the emergency screen pops with the countdown
    wobblePending      = true;
    wobblePendingUntil = millis() + WOBBLE_GRACE_MS;
    // Light the warning triangle immediately — it'll keep blinking through
    // the grace period (and into the alarm if not cancelled). Gives a
    // pocketed-phone rider a peripheral visual cue + time to hit OFF.
    matrixState   = true;
    lastBlinkTime = millis();
    drawTriangle();
    Serial.printf("Wobble detected — arming in %lu ms\n", WOBBLE_GRACE_MS);
  }

  // ---- (c) pending -> active transition ----
  // The cast to (long) makes the subtraction correctly handle millis() wraparound
  // (which only matters after ~50 days of uptime, but it's a free safety).
  if (wobblePending && (long)(millis() - wobblePendingUntil) >= 0) {
    wobblePending = false;
    setAlarm(true, "wobble (after grace)");
  }

  // ---- (d) heartbeat / node-status maintenance ----
  unsigned long now = millis();
  if (now - lastPingSent >= PING_INTERVAL) {
    lastPingSent = now;
    sendPing();                                   // ask each slave "are you there?"
  }
  // Build a fresh status bitmask from the per-slave timestamps.
  uint8_t mask = 0;
  for (int i = 0; i < NUM_SLAVES; ++i) {
    if (lastHeartbeat[i] != 0 && (now - lastHeartbeat[i]) < HEARTBEAT_TIMEOUT) {
      mask |= (1 << i);                           // slave i is online
    }
  }
  // Only publish if the mask actually changed — saves BLE traffic.
  if (mask != lastNodeStatus) {
    lastNodeStatus = mask;
    publishNodeStatus(mask);
    Serial.printf("Node status: 0x%02X\n", mask);
  }

  // ---- (e) hazard-triangle blink ----
  // Blink during BOTH the wobble grace period and the active alarm. That
  // way the rider sees the warning triangle as soon as the countdown
  // begins, not only after the siren fires.
  if (alarmActive || wobblePending) {
    if (now - lastBlinkTime >= (unsigned long)blinkInterval) {
      lastBlinkTime = now;
      matrixState   = !matrixState;
      if (matrixState) drawTriangle();
      else { matrix.clear(); matrix.writeDisplay(); }
    }
  }
}

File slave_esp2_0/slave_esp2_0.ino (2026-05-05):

// ============================================================================
//  MC Alarm — Slave (hazard-light relay) firmware
//  Board: ESP32-C3 DevKitM-1
//  Arduino-ESP32 core: 3.x  (callback signatures changed in 3.0)
// ============================================================================
//
//  WHAT THIS DEVICE DOES
//  ---------------------
//  This is a "dumb" relay node. It has no sensors, no buttons, no display,
//  no BLE — only a relay and an ESP-NOW radio. Its entire job is:
//
//    - listen for messages from the master
//    - flash a 5V relay (which switches the bike's hazard lights) when
//      the master says "alarm is on"
//    - reply to pings so the master knows we're alive
//
//
//  PROTOCOL (must match the master's ESP-NOW protocol exactly)
//  -----------------------------------------------------------
//
//    msgType  | direction        | meaning
//    ---------+------------------+------------------------------------------
//    0x01     | master -> slave  | "alarm is now on / off" (alarmActive)
//    0x02     | master -> slave  | "are you alive?" + state sync
//    0x03     | slave  -> master | "yes I'm alive, I am node N"
//
//
//  RELAY WIRING
//  ------------
//  Relay polarity differs between modules and how you wire the lights.
//  Don't hard-code HIGH/LOW; use the RELAY_ON / RELAY_OFF constants
//  below and adjust them once for your hardware.
//
//  Current setting matches our hardware:
//      digitalWrite(relayPin, HIGH) -> hazard lights ON
//      digitalWrite(relayPin, LOW)  -> hazard lights OFF
//
//  If your light is on at boot when you don't expect it to be, just
//  swap the values of RELAY_ON and RELAY_OFF.
//
//
//  PER-SLAVE CONFIGURATION
//  -----------------------
//  Before flashing each slave, set NODE_ID below. Each slave MUST have a
//  unique NODE_ID (1, 2, 3, …). The master uses this to track which slave
//  is online in its node-status bitmask.
//
// ============================================================================


// ----------------------------------------------------------------------------
// 1. INCLUDES
// ----------------------------------------------------------------------------
#include <esp_now.h>     // peer-to-peer wifi protocol
#include <WiFi.h>        // ESP-NOW needs the wifi radio in STA mode
#include <string.h>      // memcpy()


// ----------------------------------------------------------------------------
// 2. CONFIGURATION
// ----------------------------------------------------------------------------
// >>> CHANGE THIS PER SLAVE BOARD <<<
#define NODE_ID 1        // each slave must have a unique id (1, 2, 3, …)

// Relay control pin.
const int relayPin = 18;

// Polarity. Swap these two if the light is on at boot or doesn't switch
// when expected.
const int RELAY_ON  = HIGH;   // pin level that lights the hazards
const int RELAY_OFF = LOW;    // pin level that turns them off

// Hazard-light blink rate. 750 ms on, 750 ms off (~0.67 Hz). Matches the
// master so visually they all flash together.
const unsigned long BLINK_INTERVAL = 750;


// ----------------------------------------------------------------------------
// 3. ESP-NOW PROTOCOL  (must match master)
// ----------------------------------------------------------------------------
#define MSG_ALARM_STATE 0x01
#define MSG_PING        0x02
#define MSG_HEARTBEAT   0x03

// Same struct as the master. __attribute__((packed)) ensures byte layout
// is identical on both sides (no padding inserted by the compiler).
typedef struct __attribute__((packed)) struct_message {
    uint8_t msgType;
    bool    alarmActive;
    uint8_t nodeId;
} struct_message;

struct_message rxMsg;     // incoming buffer
struct_message txMsg;     // outgoing buffer (heartbeats)


// ----------------------------------------------------------------------------
// 4. STATE
// ----------------------------------------------------------------------------
// Whether the relay should currently be flashing. Set by master messages.
bool shouldBlink = false;

// We only register the master as a peer the first time we hear from it,
// because we don't know the master's MAC at compile time.
bool    masterPeerRegistered = false;
uint8_t masterMac[6];

// Non-blocking blink scheduler.
unsigned long lastBlinkToggle = 0;
bool          relayOn         = false;     // current physical state of the relay


// ----------------------------------------------------------------------------
// 5. HELPERS
// ----------------------------------------------------------------------------
// First time we hear from the master we capture its MAC and register it as
// an ESP-NOW peer. Without this we couldn't send anything BACK to the
// master (heartbeats would silently fail).
void ensureMasterPeer(const uint8_t *mac) {
  if (masterPeerRegistered) return;
  memcpy(masterMac, mac, 6);

  esp_now_peer_info_t peer = {};
  memcpy(peer.peer_addr, mac, 6);
  peer.channel = 0;        // 0 = "current channel"
  peer.encrypt = false;
  if (esp_now_add_peer(&peer) == ESP_OK) {
    masterPeerRegistered = true;
    Serial.println("Master peer registered");
  }
}

// Reply to a ping with our id. The master uses this to mark us "online"
// in its node-status bitmask, which it forwards to the phone.
void sendHeartbeat() {
  if (!masterPeerRegistered) return;       // no point — we don't know who to send to
  txMsg.msgType     = MSG_HEARTBEAT;
  txMsg.alarmActive = shouldBlink;         // echo our current state for diagnostics
  txMsg.nodeId      = NODE_ID;
  esp_now_send(masterMac, (uint8_t *)&txMsg, sizeof(txMsg));
}


// ----------------------------------------------------------------------------
// 6. ESP-NOW RECEIVE CALLBACK
// ----------------------------------------------------------------------------
// Called by the wifi driver whenever an ESP-NOW packet arrives.
// Note: signature changed in Arduino-ESP32 core 3.0; old (uint8_t*, …)
// signatures will compile but never be called.
void OnDataRecv(const esp_now_recv_info *info, const uint8_t *data, int len) {
  if (len != sizeof(struct_message)) return;     // ignore malformed packets
  memcpy(&rxMsg, data, sizeof(rxMsg));

  // info->src_addr is the master's MAC. Save it the first time so we can
  // reply later.
  ensureMasterPeer(info->src_addr);

  switch (rxMsg.msgType) {
    case MSG_ALARM_STATE:
      shouldBlink = rxMsg.alarmActive;
      // If the master says "off", switch the relay off immediately —
      // don't wait for the next BLINK_INTERVAL tick.
      if (!shouldBlink) {
        digitalWrite(relayPin, RELAY_OFF);
        relayOn = false;
      }
      break;

    case MSG_PING:
      // Pings double as state sync — if a previous MSG_ALARM_STATE got
      // lost, the next ping will fix our state. Then send the heartbeat
      // so the master knows we're alive.
      shouldBlink = rxMsg.alarmActive;
      sendHeartbeat();
      break;
  }
}
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

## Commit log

2026-04-23 Master and slave code
    master
    - sends signal to slave to make it blink
    - starts the speaker
    - buttons to turn it off and on
    Slave
    - Receives signal and starts the blinking
2026-04-23 Updated
    Updated for led light in main
2026-04-29 Sync Flutter app, add toolchain docs, harden wobble detector
    - Sync app/ from working copy: 5s wobble countdown + cancel handling,
    HAZARDS confirmation dialog, single-slave dashboard, auto-jump to
    dashboard on connect, BLE wobble dedup
    - Master firmware: 5s arming grace before alarm fires, 3s post-alarm
    cooldown, 3s startup grace, threshold raised to 2.5 rad/s, both
    samples must clear threshold for a flip to count, speaker silenced
    at the very start of setup() to avoid boot-time noise
    - Slave firmware: heartbeat protocol + non-blocking blink (matches
    master's MSG_ALARM_STATE / MSG_PING / MSG_HEARTBEAT)
    - README docs at root and in app/ pin Flutter 3.24.5 + plugin versions
    to do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
    [master.ino, slave_esp2_0.ino]
2026-05-01 Fix I2C wiring on master + demo-tune wobble detector
    - Switch to shared I2C bus (SDA=2, SCL=3) for both MPU-6050 (0x68) and
    the LED matrix (0x70). Previous config had MPU pins swapped and the
    matrix on a separate bus that didn't exist on the actual hardware,
    which is why "MPU6050 not found" kept appearing.
    - Drop the per-call Wire.begin() switching now that everything's on one
    bus.
    - Add an mpuOk flag — wobble detection is fully disabled if the MPU
    isn't found at boot, so a missing sensor can never falsely trigger
    the alarm via garbage memory reads.
    - Sanity-cap rotation readings at 9 rad/s (gyro is ±8.73 rad/s
    full-scale; anything bigger is impossible and indicates bad data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
    [master.ino]
2026-05-01 Fix first-wobble swallow + slave relay polarity, drop redundant guards
    App:
    - Read wobble characteristic value during connect to use as baseline
    instead of blindly skipping the first stream emission. The skip-first
    logic was swallowing the very first wobble of a session whenever the
    BLE stack didn't pre-emit a cached value.
    Master:
    - Drop the "both samples must clear threshold" guard in checkForWobble.
    It was a workaround for garbage data from a disconnected MPU; with
    the wiring fixed it just made the detector slower to start counting
    flips.
    Slave:
    - Use named RELAY_ON / RELAY_OFF constants instead of hard-coded
    HIGH/LOW. Light is now off by default at boot and only turns on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
    [master.ino, slave_esp2_0.ino]
2026-05-05 Refresh README with final hardware, pin map, and wobble flow
    - Fix master pin map: MPU + LED matrix share I2C bus on GPIO 2/3
    (previously documented as separate buses, which never matched the
    actual wiring)
    - Document the slave's RELAY_ON / RELAY_OFF polarity constants
    instead of the old "active-low" assumption
    - Add the laser-cut MDF base panels, laser-cut acrylic Segway plate,
    and the bulb end-cap enclosures to the mechanical hardware list
    - Split the wobble detector profile into demo (1.0 rad/s, 3 flips,
    800 ms) and production (2.5 rad/s, 4 flips, 600 ms) tables, with
    a note to raise the values before on-bike use
    - Add academic context: ITI60020 Digital Fabrication and Making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
2026-05-05 Add launcher icon, restore siren tone, light matrix during grace period
    Master firmware:
    - Restore siren tone to 1200 Hz (was at 100 Hz from earlier debugging,
    practically inaudible)
    - Light the LED hazard triangle the moment a wobble is detected, not
    only after the grace period elapses. Gives a rider with the phone
    in a pocket a peripheral visual cue and time to hit OFF.
    - Clear the matrix when the wobble is cancelled during the grace
    period (via OFF button or app STOP), since the alarm never actually
    fired.
    - Sync app/pubspec.yaml from working copy: adds flutter_launcher_icons
    dev dependency and the launcher icon configuration.
    - Add the icon source assets in app/assets/i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
    [master.ino]
2026-05-05 add 3d models
    addes 3d models for attachment, clamps, comp_box, user_box and reim
    [ClampMain.3mf, ClampMainWstaff.3mf, User_box_w_attachment.3mf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]
2026-05-05 add drawings and lacer cutter file
    add drawings of component box, user box, clams, and added the laser cutter file for acrylic lids for both component and user box.
